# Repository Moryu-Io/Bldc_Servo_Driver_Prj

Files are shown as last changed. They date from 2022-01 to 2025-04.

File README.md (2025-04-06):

# BLDC Servo Driver Project

## 概要
STM32マイコンを使用してBLDCを駆動する制御プログラム  
マイコン種類が変わっても、なるべくペリフェラル設定のメンテのみで動作が可能なように実装  
現在のメイン開発は`G431CB_FSDmini`

新ROBO-剣出場ロボット[Quinque](https://www.robo-one.com/rankings/view/1127)のアーム部モータに採用  
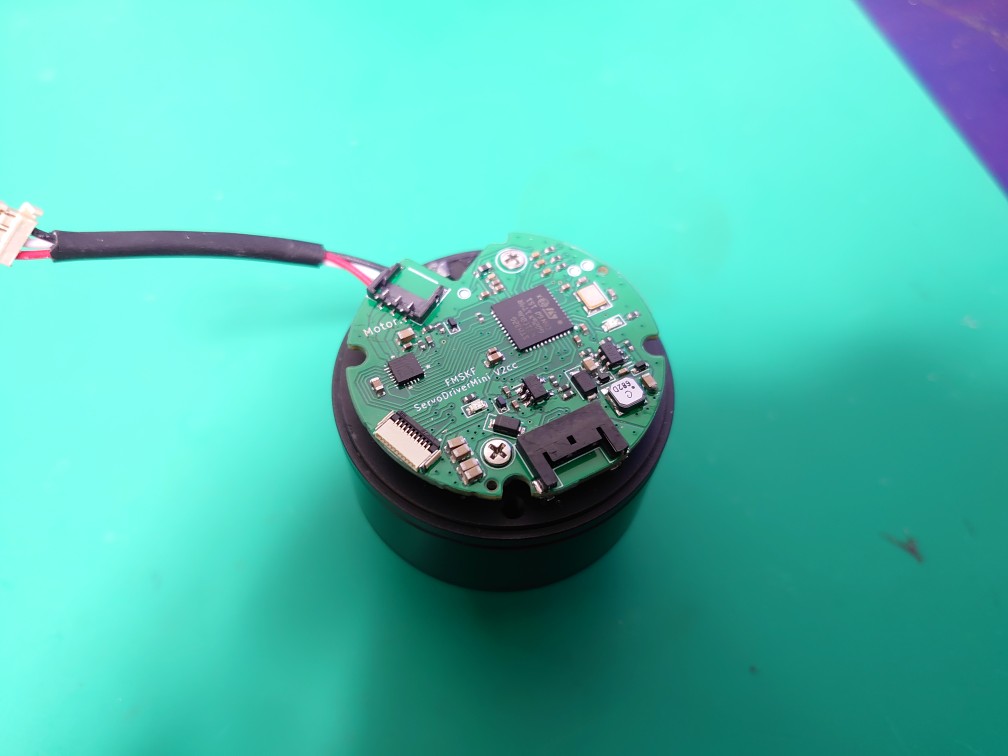
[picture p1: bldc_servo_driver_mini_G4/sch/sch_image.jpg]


## フォルダ構成
| フォルダ名 | 説明 |
| --- | --- |
|bldc_servo_driver_mini_F4|STM32F405を使用したBLDCドライバ用コード(未メンテ)|
|bldc_servo_driver_mini_G4|STM32G4系マイコンを使用したBLDCドライバ用コード|
|bldc_servo_driver_mini_H7|STM32H7を使用したBLDCドライバ用コード(未作成)|
|bldc_servo_driver_stspin32g4|STM32G4(STSPIN32G4)を使用したBLDCドライバ用コード|
|common|各マイコンで共通のコード。例えばBLDCベクトル制御ロジック|
|python|各テストコマンドをpython経由で使用するためのスクリプト群|

## 使い方(Windows)
1. 必要Toolのインストール
    - VScode
    - GNU ARM Embedded Toolchain
        - [公式サイト](https://developer.arm.com/tools-and-software/open-source-software/developer-tools/gnu-toolchain/gnu-rm/downloads)
        - Projectとしては2020-q4を使っている。本PJのtask.jsonに記載のディレクトリを変えれば別Verでも使えるはず
        - zip版をDLし, C:\Tools\gcc-arm-none-eabi-9-20XX-qX-major-win32\bin など分かりやすいように配置し、Path を通しておく
    - makeするための何か
        - make for windows, msys2, wslなど。自分は現状msys2でmakeを使えるようにしている
        - 本PJのtask.jsonでは`C:\\msys64\\usr\\bin\\make.exe` がある前提で記載している
    - STM32CubeProgrammer
        - [公式サイト]https://www.st.com/ja/development-tools/stm32cubeprog.html
        - STM32マイコンへのFW書き込みやフラッシュ制御などができる
        - 本PJのtask.jsonではコマンドライン用のexeを利用してマイコンへの書き込みを行っている

2. クローン
    - `git clone https://github.com/Moryu-Io/Bldc_Servo_Driver_Prj.git`など
    - VSCode のタスク構成もついてくるはず

3. VSCode Workspaceを開く
    - 現在は`bldc_servo_driver_G4.code-workspace`推奨

4. Ctrl+Alt+t でタスクを開き`Build project`を実行すると、ビルドができる

5. Ctrl+Alt+t でタスクを開き`cube_program`を実行すると書き込みができる

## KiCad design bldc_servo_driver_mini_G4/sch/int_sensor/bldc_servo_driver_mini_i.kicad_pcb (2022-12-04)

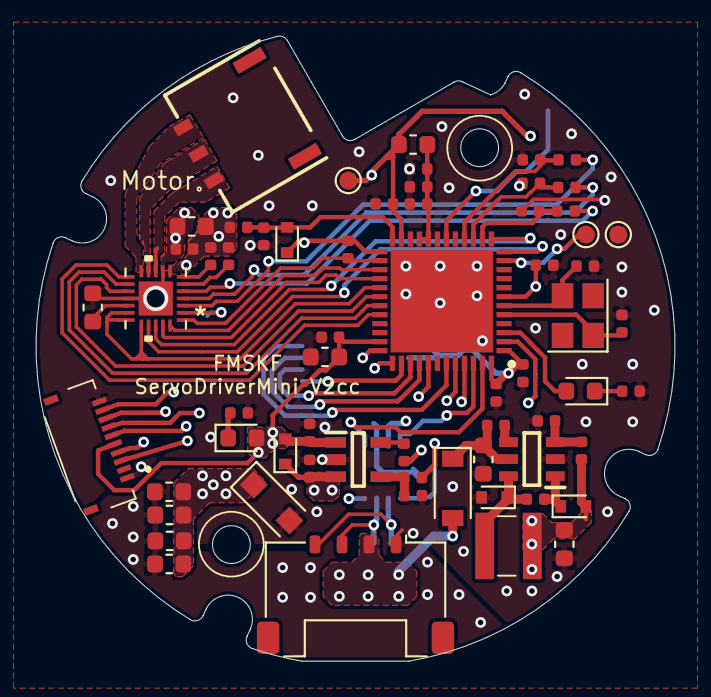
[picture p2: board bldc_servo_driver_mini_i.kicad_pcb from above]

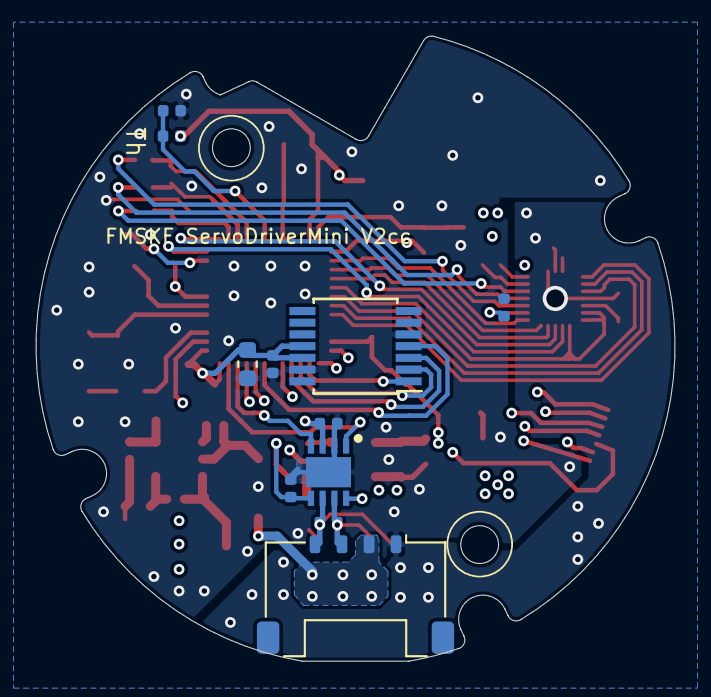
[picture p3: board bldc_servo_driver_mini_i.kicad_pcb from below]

Board: 4 copper layers, 35.5 x 34.7 mm, 74 parts (11 on the bottom side), 56 nets.

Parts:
C1, C2, C3, C4, C7, C8, C10, C16, C20, C21, C24, C32: 0.1u; C_0402_1005Metric
C5, C11, C15, C22, C28, C29, C30, C31: 10u; C_0603_1608Metric
C6, C13: 0.01u; C_0402_1005Metric
C9, C14, C23: 1u; C_0402_1005Metric
C12, C25: 4.7u; C_0603_1608Metric
C17, C18, C19: 220pF; C_0402_1005Metric
C26, C27: 8p; C_0402_1005Metric
D1: D_Schottky; D_SOD-123F
D2: PMEG6010AESBYL; D_SOD-123
D3, D4, D9: D_Schottky; D_SOD-523
D5: BAT30KFILM; D_SOD-523
D6, D8: LED; LED_0603_1608Metric
IC1: ST730MR; SOT95P280X145-5N
IC2: LT1616ES6#TRMPBF; SOT95P280X90-6N
IC3: TLT9251VLEXUMA1; SON65P300X300X110-9N
IC4: STM32G4xxyU; QFN50P700X700X60-49N-D
J1: 1-2328702-0; 123287020
J2, J3: Conn_01x04; Molex_Pico-Lock_504050-0491_1x04-1MP_P1.50mm_Horizontal
J7: DF65-3P-1.7V_21_
L1: L; L_0603_1608Metric
L2: 4.7u; LPS3314332MRC
R3, R4, R16, R18, R20: 10k; R_0402_1005Metric
R5: 47k; R_0402_1005Metric
R6: 27k; R_0402_1005Metric
R7: 470k; R_0402_1005Metric
R8: 33k; R_0402_1005Metric
R9, R10, R11: 510; R_0402_1005Metric
R12, R14: 330; R_0402_1005Metric
R15: 60; R_0402_1005Metric
R17: 0; R_0402_1005Metric
R19: 30.1k or 51k(MP2359); R_0402_1005Metric
TH1: Thermistor_NTC; R_0402_1005Metric
TP1, TP2, TP3: TestPoint; TestPoint_Pad_D1.0mm
U1: AS5048A; TSSOP-14_4.4x5mm_P0.65mm
U2: PDRV8311HRRWR
Y1: Crystal; Crystal_SMD_Abracon_ABM8G-4Pin_3.2x2.5mm

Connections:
+3V3: C1.1, C2.1, C5.2, C7.2, C9.1, C10.1, C12.1, C20.1, C21.1, C32.2, D3.2, D5.1, D8.2, IC1.1, IC3.5, IC4.1, IC4.23, IC4.25, IC4.35, IC4.48, J1.5, L1.2, R5.2, R16.1, R18.2, TP1.1, U1.11, U1.12, U2.2
+5V: C8.1, C16.1, C29.2, D3.1, D9.2, IC1.3, IC3.3, L2.2, R4.1, R19.2
+12V: C11.2, C22.1, C23.1, C24.1, C28.2, C30.2, C31.2, D1.1, D2.2, J2.2, J3.2, R7.2, R17.1, U2.8
/CAN1_EN: IC3.8, IC4.2
/CAN1_RX: IC3.4, IC4.46
/CAN1_TX: IC3.1, IC4.47
/CAN_H: IC3.7, J2.3, J3.3, R15.2
/CAN_L: IC3.6, J2.4, J3.4, R15.1
/CurrentSensA: C17.1, IC4.14, R9.1
/CurrentSensB: C18.1, IC4.15, R10.1
/CurrentSensC: C19.1, IC4.16, R11.1
/DAC_O1_GAIN: IC4.12, U2.21
/DAC_O2_SLEW: IC4.13, U2.22
/GPIO_MODE: IC4.28, U2.23
/LED1: D6.2, IC4.3
/M_OUTA: J7.1, U2.10
/M_OUTB: J7.2, U2.11
/M_OUTC: J7.3, U2.12
/NRST: C3.1, IC4.7, J1.4
/Potentio_Sens: IC4.11, TP2.1
/SOA: R9.2, U2.5
/SOB: R10.2, U2.4
/SOC: R11.2, U2.3
/SPI3_CS: IC4.38, U1.1
/SPI3_MISO: IC4.40, U1.3
/SPI3_MOSI: IC4.43, U1.4
/SPI3_SCK: IC4.39, U1.2
/SWCLK: IC4.37, J1.7
/SWDIO: IC4.36, J1.6
/SWO: IC4.41, J1.3
/TIM1_CH1: IC4.30, U2.15
/TIM1_CH1N: IC4.29, U2.18, U2.19, U2.20
/TIM1_CH2: IC4.31, U2.14
/TIM1_CH3: IC4.32, U2.13
/Temp_Sens: IC4.18, R18.1, TH1.1
/USART1_RX: IC4.45, J1.9
/USART1_TX: IC4.44, J1.8
/Vm_Sens: D5.2, IC4.24, R7.1, R8.2
/nFAULT: IC4.26, R16.2, U2.1
/nSLEEP: IC4.27, U2.24
GND: C1.2, C2.2, C3.2, C4.2, C5.1, C7.1, C8.2, C9.2, C10.2, C11.1, C12.2, C13.2, C14.2, C15.1, C16.2, C17.2, C18.2, C19.2, C20.2, C21.2, C22.2, C24.2, C25.1, C26.1, C27.2, C28.1, C29.1, C30.1, C31.1, C32.1, D1.2, D4.2, IC1.2, IC2.2, IC3.2, IC3.9, IC4.49, J1.1, J1.10, J2.1, J3.1, R6.1, R8.1, R12.1, R14.1, R20.1, TH1.2, TP3.1, U1.5, U1.13, U2.9, U2.16, U2.25
unnamed: C6.1, D9.1, IC2.1
unnamed: C6.2, D4.1, IC2.6, L2.1
unnamed: C4.1, C13.1, C14.1, IC4.20, IC4.21, L1.1
unnamed: C15.2, D2.1, IC2.5, R3.2
unnamed: C23.2, U2.6
unnamed: C25.2, U2.17
unnamed: C26.2, IC4.5, Y1.1
unnamed: C27.1, IC4.6, Y1.3
unnamed: D6.1, R12.2
unnamed: D8.1, R14.2
unnamed: IC1.4, R5.1, R6.2
unnamed: IC1.5, R4.2
unnamed: IC2.3, R19.1, R20.2
unnamed: IC2.4, R3.1
unnamed: R17.2, U2.7

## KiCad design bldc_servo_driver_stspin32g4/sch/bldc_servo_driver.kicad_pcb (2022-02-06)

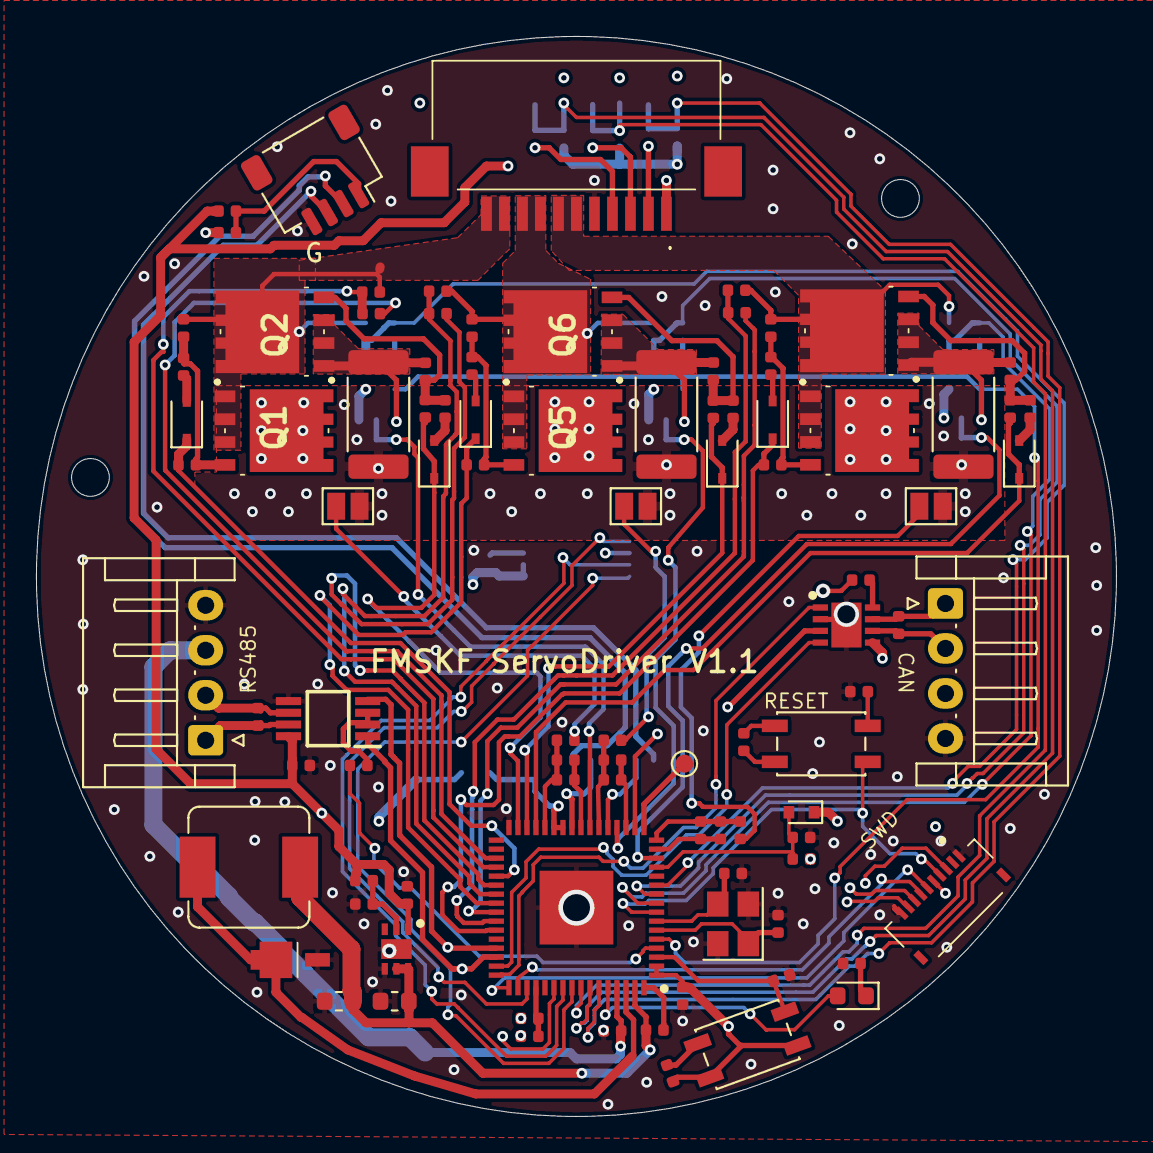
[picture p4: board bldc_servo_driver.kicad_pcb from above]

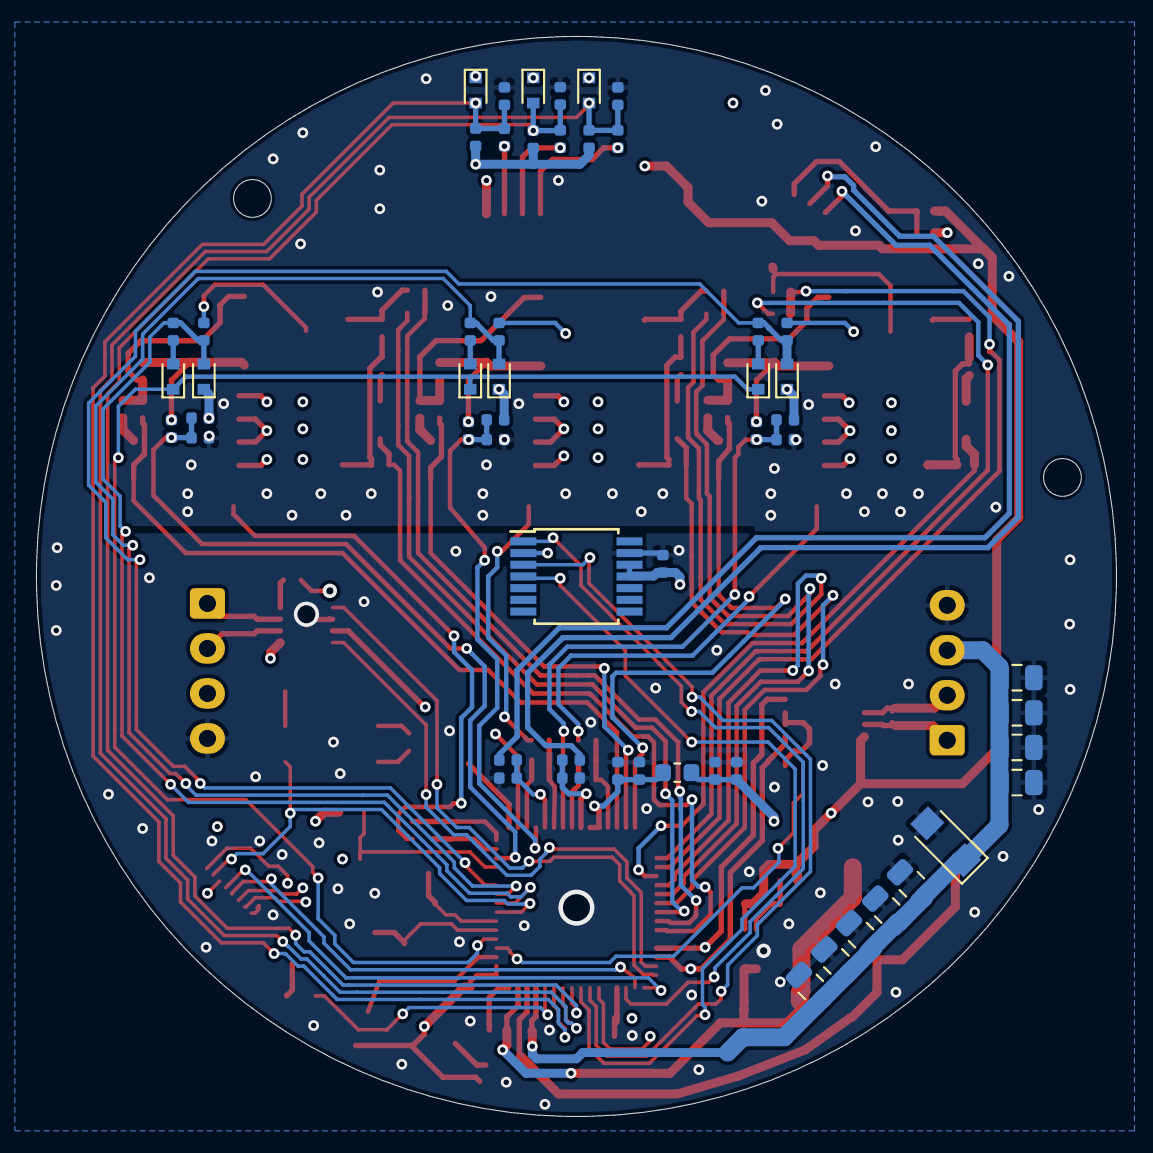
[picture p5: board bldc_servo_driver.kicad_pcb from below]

Board: 4 copper layers, 60.0 x 60.0 mm, 150 parts (54 on the bottom side), 97 nets.

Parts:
C1, C2, C3: 10p; C_0402_1005Metric
C4, C8, C20, C25, C50, C52: 0.1u; C_0402_1005Metric
C7: 2.2u; C_0402_1005Metric
C9, C26: 10u; C_0603_1608Metric
C10, C27, C28, C42: 1u; C_0402_1005Metric
C11: 0.01u; C_0402_1005Metric
C12, C14, C15, C17, C19, C29, C30, C31, C32: 22u; C_0805_2012Metric
C13, C16, C22: C; C_0402_1005Metric
C18, C21, C46: 100p; C_0402_1005Metric
C23, C24: 0.001u; C_0402_1005Metric
C53: 4.7u; C_0402_1005Metric
D1, D2, D3, D4, D5, D6, D7, D8, D9, D10: BAT30KFILM; D_SOD-523
D11: SMM4F24A; D_SMF
D12: STPS1L40M
D13: LED; LED_0603_1608Metric
D17, D18, D19, D20, D21, D22: BAT48JFILM; D_SOD-323
H1, H2: MountingHole; MountingHole_2.1mm
IC1: STSPIN32G4; QFN50P900X900X100-65N-D
IC3: LDFMPVR; SON65P200X200X100-7N-D
IC5: SN65HVD485EDGKR; SOP65P490X110-8N
IC6: TLT9251VLEXUMA1; SON65P300X300X110-9N
J1: 1-2328702-0; 123287020
J2, J3: Conn_01x04; JST_EH_S4B-EH_1x04_P2.50mm_Horizontal
J4: 52271-1179; 522711179
J5: Conn_01x04; JST_SH_SM04B-SRSS-TB_1x04-1MP_P1.00mm_Horizontal
JP1, JP2, JP3: SolderJumper_2_Bridged; SolderJumper-2_P1.3mm_Open_Pad1.0x1.5mm
L1: L; L_0603_1608Metric
L2: 33u; L_Sumida_CDMC6D28_7.25x6.5mm
Q1, Q2, Q3, Q4, Q5, Q6: STL180N6F7; STL140N6F7
R1, R5, R7: 1.8k; R_0402_1005Metric
R2, R3, R4, R6, R10, R11, R25, R51, R53, R54, R56, R68, R69, R71: 10k; R_0402_1005Metric
R8: 470k; R_0402_1005Metric
R9: 33k; R_0402_1005Metric
R12, R13, R14: 2.2k; R_0402_1005Metric
R15, R16, R17, R18, R19, R20, R70: 22k; R_0402_1005Metric
R21, R22, R23, R28, R31, R33: 1.5k; R_0402_1005Metric
R24: 52.3k; R_0402_1005Metric
R26, R42: 1k; R_0402_1005Metric
R27, R29, R32: 11k; R_0402_1005Metric
R30, R34, R35, R40, R41, R44, R45, R47, R55, R57, R60, R61, R65, R66: 0; R_0402_1005Metric
R36: 60; R_0402_1005Metric
R37: 120; R_0402_1005Metric
R43: 330; R_0402_1005Metric
R46, R49, R50, R52, R64, R67: 33; R_0402_1005Metric
R48, R58, R59: 0.003; R_2512_6332Metric
R62, R63: 1.6k; R_0402_1005Metric
SW1, SW2: SW_SPST; SW_SPST_EVQP2
TP1: TestPoint; TestPoint_Pad_D1.0mm
U1: AS5048A; TSSOP-14_4.4x5mm_P0.65mm
Y1: ABM8G-25MHZ-18-D2Y-T; Crystal_SMD_Abracon_ABM8G-4Pin_3.2x2.5mm

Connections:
+3.3VA: C10.2, C11.2, IC1.26, IC1.27, L1.2
+3V3: C4.1, C8.1, C50.1, C52.1, C53.1, D1.1, D2.1, D3.1, D4.1, D5.1, D7.1, D8.1, IC1.1, IC1.2, IC6.5, J1.5, L1.1, R6.2, R10.2, R11.2, R15.1, R17.1, R19.1, R41.1, R70.1, SW2.1, U1.11, U1.12
+5V: C7.1, C22.1, IC3.1, IC5.8, IC6.3, J4.1, R24.2, R40.1
+BATT: C12.1, C14.1, C15.1, C17.1, C19.1, C20.1, C29.1, C30.1, C31.1, C32.1, D11.1, IC1.61, J2.3, J3.3, Q1.5, Q1.6, Q1.7, Q1.8, Q1.9, Q3.5, Q3.6, Q3.7, Q3.8, Q3.9, Q5.5, Q5.6, Q5.7, Q5.8, Q5.9, R8.2
/subSch_3phasebridge/BOOT0: C42.1, IC1.41
/subSch_3phasebridge/BOOT1: C28.1, IC1.38
/subSch_3phasebridge/BOOT2: C27.1, IC1.35
/subSch_3phasebridge/GHS0: D19.1, IC1.43, R50.2
/subSch_3phasebridge/GHS1: D20.1, IC1.40, R64.2
/subSch_3phasebridge/GHS2: D17.1, IC1.37, R46.2
/subSch_3phasebridge/GLS0: D21.1, IC1.29, R52.2
/subSch_3phasebridge/GLS1: D22.1, IC1.30, R67.2
/subSch_3phasebridge/GLS2: D18.1, IC1.31, R49.2
/subSch_3phasebridge/MotorD0: J4.6, J4.7, Q3.1, Q3.2, Q3.3, Q4.5, Q4.6, Q4.7, Q4.8, Q4.9, R2.1, R54.2, R55.1
/subSch_3phasebridge/MotorD1: J4.8, J4.9, Q5.1, Q5.2, Q5.3, Q6.5, Q6.6, Q6.7, Q6.8, Q6.9, R3.1, R57.1, R68.2
/subSch_3phasebridge/MotorD2: J4.10, J4.11, Q1.1, Q1.2, Q1.3, Q2.5, Q2.6, Q2.7, Q2.8, Q2.9, R4.1, R44.1, R51.2
/subSch_3phasebridge/VshuntU+: Q4.1, Q4.2, Q4.3, R21.2, R56.2, R58.1
/subSch_3phasebridge/VshuntU-: JP2.2, R28.2
/subSch_3phasebridge/VshuntV+: Q6.1, Q6.2, Q6.3, R22.2, R59.1, R69.2
/subSch_3phasebridge/VshuntV-: JP3.2, R31.2
/subSch_3phasebridge/VshuntW+: Q2.1, Q2.2, Q2.3, R23.2, R48.1, R53.2
/subSch_3phasebridge/VshuntW-: JP1.2, R33.2
/subSch_extcon/ANALOG0: J5.2, R62.1
/subSch_extcon/ANALOG1: J5.3, R63.1
/subSch_extcon/ANALOG2: IC1.17, TP1.1
/subSch_extcon/CAN_EN: IC1.4, R34.1, R35.2
/subSch_extcon/COM_BUS3: IC1.45, IC5.4, J1.8
/subSch_extcon/COM_BUS4: IC1.46, IC5.1, J1.9
/subSch_extcon/Hall_0: J4.3, R1.1
/subSch_extcon/Hall_1: J4.4, R5.1
/subSch_extcon/Hall_2: J4.2, R7.1
/subSch_extcon/USART_EN: IC5.2, IC5.3, R34.2
/subSch_mcu/CAN1_RX: IC1.47, IC6.4
/subSch_mcu/CAN1_TX: IC1.48, IC6.1
/subSch_mcu/HALL_AD_A: C23.1, IC1.25, R62.2
/subSch_mcu/HALL_AD_B: C24.1, IC1.21, R63.2
/subSch_mcu/HALL_U: C1.1, D5.2, IC1.57, R1.2, R6.1
/subSch_mcu/HALL_V: C2.1, D7.2, IC1.58, R5.2, R10.1
/subSch_mcu/HALL_W: C3.1, D8.2, IC1.59, R7.2, R11.1
/subSch_mcu/LED: D13.2, IC1.60
/subSch_mcu/MCU_OUT0: C42.2, IC1.42, R55.2
/subSch_mcu/MCU_OUT1: C28.2, IC1.39, R57.2
/subSch_mcu/MCU_OUT2: C27.2, IC1.36, R44.2
/subSch_mcu/MCU_SPI_BUS0: IC1.56, U1.4
/subSch_mcu/MCU_SPI_BUS1: IC1.55, U1.3
/subSch_mcu/MCU_SPI_BUS2: IC1.18, U1.2
/subSch_mcu/MCU_SPI_BUS3: IC1.51, U1.1
/subSch_mcu/MCU_SWD_BUS0: IC1.50, J1.7
/subSch_mcu/MCU_SWD_BUS1: IC1.49, J1.6
/subSch_mcu/MCU_SWD_BUS2: C25.1, IC1.8, J1.4, SW1.1
/subSch_mcu/MCU_SWD_BUS3: IC1.54, J1.3
/subSch_mcu/MCU_VBAT_MON: D4.2, IC1.13, R8.1, R9.2
/subSch_mcu/OP1M: C46.2, IC1.16, R27.2, R28.1
/subSch_mcu/OP1O: C46.1, IC1.15, R27.1
/subSch_mcu/OP2M: C18.2, IC1.22, R29.2, R31.1
/subSch_mcu/OP2O: C18.1, IC1.19, R29.1
/subSch_mcu/OP3M: C21.2, IC1.28, R32.2, R33.1
/subSch_mcu/OP3O: C21.1, IC1.24, R32.1
/subSch_mcu/SCREF: IC1.52, R70.2, R71.1
/subSch_mcu/SW: D12.1, D12.2, IC1.62, L2.2
/subSch_mcu/USER_SW: C8.2, IC1.3, R26.1, SW2.2
/subSch_onboardsensing/BEMF0: D1.2, IC1.9, R2.2, R12.1
/subSch_onboardsensing/BEMF1: D2.2, IC1.10, R3.2, R13.1
/subSch_onboardsensing/BEMF2: D3.2, IC1.11, R4.2, R14.1
/subSch_onboardsensing/CurFb+_0: IC1.14, R15.2, R16.1, R21.1
/subSch_onboardsensing/CurFb+_1: IC1.20, R17.2, R18.1, R22.1
/subSch_onboardsensing/CurFb+_2: IC1.23, R19.2, R20.1, R23.1
/subSch_onboardsensing/GPIO_BEMF: D6.1, D9.1, D10.1, IC1.5
GND: C1.2, C2.2, C3.2, C4.2, C7.2, C9.2, C10.1, C11.1, C12.2, C13.2, C14.2, C15.2, C16.1, C17.2, C19.2, C20.2, C22.2, C23.2, C24.2, C26.2, C29.2, C30.2, C31.2, C32.2, C50.2, C52.2, C53.2, D11.2, D12.3, IC1.32, IC1.65, IC3.4, IC3.7, IC5.5, IC6.2, IC6.9, J1.1, J1.10, J2.4, J3.4, J4.5, J5.4, JP1.1, JP2.1, JP3.1, R9.1, R16.2, R18.2, R20.2, R25.1, R26.2, R42.2, R43.2, R48.2, R58.2, R59.2, R71.2, U1.13, Y1.2, Y1.4
unnamed: C13.1, IC1.6, Y1.1
unnamed: C16.2, IC1.7, Y1.3
unnamed: C25.2, R42.1, SW1.2
unnamed: D6.2, R12.2
unnamed: D9.2, R13.2
unnamed: D10.2, R14.2
unnamed: D13.1, R43.1
unnamed: D17.2, R45.2
unnamed: D18.2, R47.2
unnamed: D19.2, R60.2
unnamed: D20.2, R61.2
unnamed: D21.2, R65.2
unnamed: D22.2, R66.2
unnamed: IC1.64, R30.2
unnamed: IC3.2, R24.1, R25.2
unnamed: IC5.6, J2.2, R36.2
unnamed: IC5.7, J2.1, R36.1
unnamed: IC6.6, J3.2, R37.1
unnamed: IC6.7, J3.1, R37.2
unnamed: IC6.8, R35.1
unnamed: J5.1, R40.2, R41.2
unnamed: Q1.4, R45.1, R46.1, R51.1
unnamed: Q2.4, R47.1, R49.1, R53.1
unnamed: Q3.4, R50.1, R54.1, R60.1
unnamed: Q4.4, R52.1, R56.1, R65.1
unnamed: Q5.4, R61.1, R64.1, R68.1
unnamed: Q6.4, R66.1, R67.1, R69.1
VCC: C9.1, C26.1, IC1.63, IC3.5, IC3.6, L2.1, R30.1

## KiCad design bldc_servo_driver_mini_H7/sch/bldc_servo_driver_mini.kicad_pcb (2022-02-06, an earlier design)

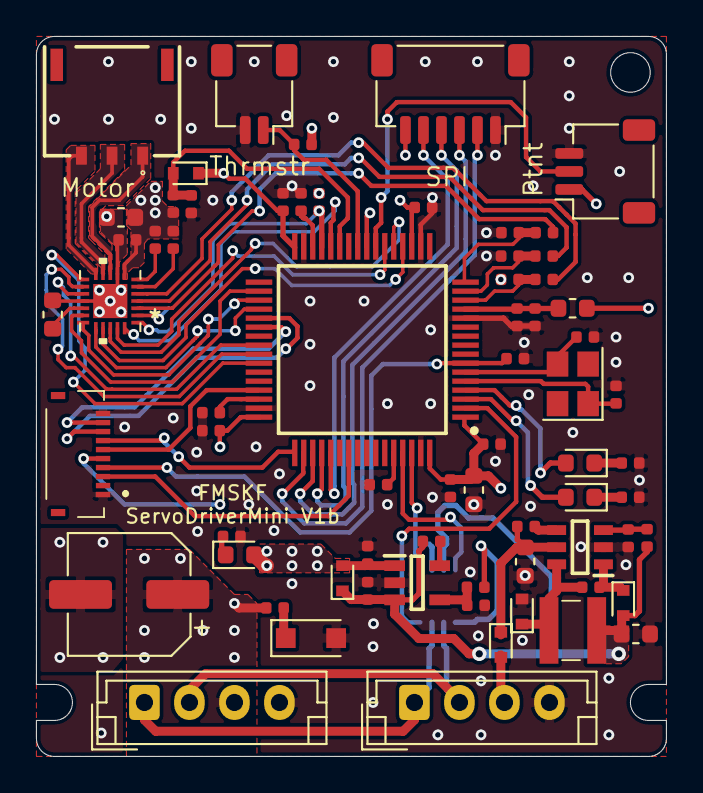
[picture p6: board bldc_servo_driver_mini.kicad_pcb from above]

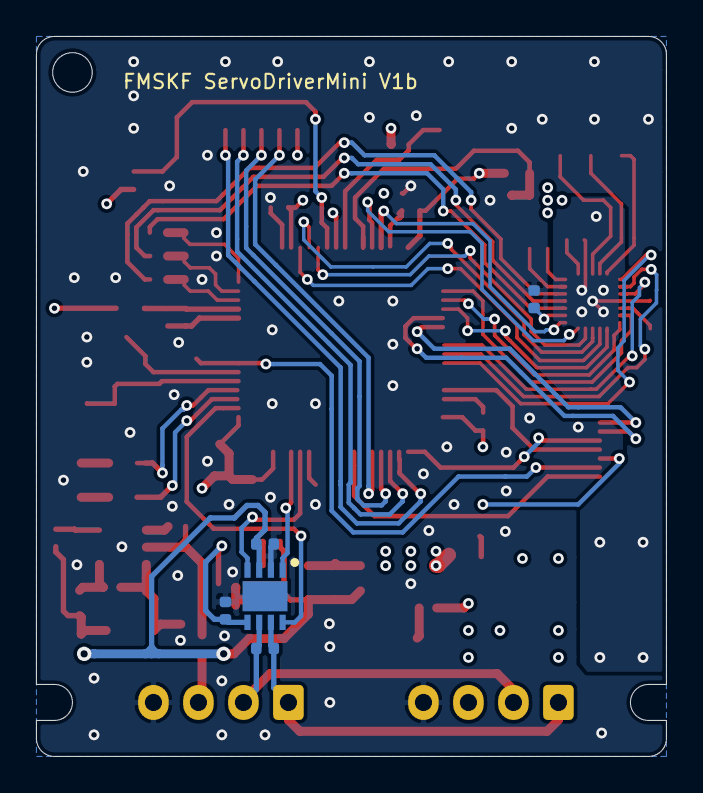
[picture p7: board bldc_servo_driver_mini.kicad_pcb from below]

Board: 4 copper layers, 35.0 x 40.0 mm, 73 parts (5 on the bottom side), 64 nets.

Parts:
C1, C3, C4, C7, C8, C10, C11, C13, C16, C20, C21, C24: 0.1u; C_0402_1005Metric
C2, C5: 2.2u; C_0402_1005Metric
C6: 0.01u; C_0402_1005Metric
C9, C14, C23: 1u; C_0402_1005Metric
C12, C25: 4.7u; C_0603_1608Metric
C15, C22, C29: 10u; C_0603_1608Metric
C17, C18, C19: 22pF; C_0402_1005Metric
C26, C27: 8p; C_0402_1005Metric
C28: 47u; CP_Elec_6.3x7.7
D1: D_Schottky; D_SOD-123F
D2: PMEG6010AESBYL; D_SOD-523
D3, D4, D9: D_Schottky; D_SOD-523
D5: BAT30KFILM; D_SOD-523
D6, D7, D8: LED; LED_0603_1608Metric
IC1: ST730MR; SOT95P280X145-5N
IC2: LT1616ES6#TRMPBF; SOT95P280X90-6N
IC3: TLT9251VLEXUMA1; SON65P300X300X110-9N
J1: 1-2328702-0; 123287020
J2, J3: Conn_01x04; JST_EH_B4B-EH-A_1x04_P2.50mm_Vertical
J4: Conn_01x06; JST_SH_SM06B-SRSS-TB_1x06-1MP_P1.00mm_Horizontal
J5: Conn_01x03; JST_SH_SM03B-SRSS-TB_1x03-1MP_P1.00mm_Horizontal
J6: Conn_01x02; JST_SH_SM02B-SRSS-TB_1x02-1MP_P1.00mm_Horizontal
J7: DF65-3P-1.7V_21_
L1: L; L_0603_1608Metric
L2: 4.7u; LPS3314332MRC
R1: 100; R_0402_1005Metric
R2: R; R_0402_1005Metric
R3, R4, R16, R18, R20: 10k; R_0402_1005Metric
R5: 47k; R_0402_1005Metric
R6: 27k; R_0402_1005Metric
R7: 470k; R_0402_1005Metric
R8: 33k; R_0402_1005Metric
R9, R10, R11, R12, R13, R14: 330; R_0402_1005Metric
R15: 60; R_0402_1005Metric
R17: 0; R_0402_1005Metric
R19: 30.1k; R_0402_1005Metric
U1: STM32H7A3RGT6; QFP50P1200X1200X160-64N
U2: PDRV8311HRRWR
Y1: Crystal; Crystal_SMD_Abracon_ABM8G-4Pin_3.2x2.5mm

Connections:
+3V3: C1.1, C4.1, C7.1, C9.1, C10.1, C11.1, C12.1, C20.1, C21.1, D3.2, D5.1, D8.2, IC1.1, IC3.5, J1.5, J4.6, J5.1, L1.2, R5.2, R16.1, R18.2, U1.1, U1.19, U1.24, U1.32, U1.48, U1.64, U2.2
+5V: C8.1, C16.1, C29.2, D3.1, D9.2, IC1.3, IC3.3, L2.2, R4.1, R19.2
+12V: C22.1, C23.1, C24.1, C28.1, D2.2, J2.3, J3.3, R1.2, R7.2, R17.1, U2.8
/CAN1_EN: IC3.8, U1.2
/CAN1_RX: IC3.4, U1.61
/CAN1_TX: IC3.1, U1.62
/CAN_H: IC3.7, J2.1, J3.1, R15.2
/CAN_L: IC3.6, J2.2, J3.2, R15.1
/CurrentSensA: C17.1, R9.1, U1.14
/CurrentSensB: C18.1, R10.1, U1.15
/CurrentSensC: C19.1, R11.1, U1.16
/DAC_O1_GAIN: U1.20, U2.21
/DAC_O2_SLEW: U1.21, U2.22
/GPIO_MODE: U1.22, U2.23
/LED1: D6.2, U1.3
/LED2: D7.2, U1.4
/M_OUTA: J7.1, U2.10
/M_OUTB: J7.2, U2.11
/M_OUTC: J7.3, U2.12
/NRST: C3.1, J1.4, U1.7
/Potentio_Sens: J5.2, U1.23
/SOA: R9.2, U2.5
/SOB: R10.2, U2.4
/SOC: R11.2, U2.3
/SPI3_CS: J4.2, U1.50
/SPI3_MISO: J4.4, U1.52
/SPI3_MOSI: J4.5, U1.53
/SPI3_SCK: J4.3, U1.51
/SWCLK: J1.7, U1.49
/SWDIO: J1.6, U1.45
/SWO: J1.3, U1.55
/TIM1_CH1: U1.40, U2.15
/TIM1_CH1N: U1.34, U2.18
/TIM1_CH2: U1.41, U2.14
/TIM1_CH2N: U1.35, U2.19
/TIM1_CH3: U1.42, U2.13
/TIM1_CH3N: U1.36, U2.20
/Temp_Sens: J6.1, R18.1, U1.25
/USART6_RX: J1.9, U1.38
/USART6_TX: J1.8, U1.37
/Vm_Sens: D5.2, R7.1, R8.2, U1.27
/nFAULT: R16.2, U1.29, U2.1
/nSLEEP: U1.28, U2.24
GND: C1.2, C2.1, C3.2, C4.2, C5.2, C7.2, C8.2, C9.2, C10.2, C11.2, C12.2, C13.2, C14.2, C15.1, C16.2, C17.2, C18.2, C19.2, C20.2, C21.2, C22.2, C24.2, C25.1, C26.1, C27.2, C28.2, C29.1, D1.2, D4.2, IC1.2, IC2.2, IC3.2, IC3.9, J1.1, J1.10, J2.4, J3.4, J4.1, J5.3, J6.2, R2.2, R6.1, R8.1, R12.1, R13.1, R14.1, R20.1, U1.12, U1.18, U1.31, U1.47, U1.63, U2.9, U2.16, U2.25
unnamed: C2.2, U1.30
unnamed: C5.1, U1.46
unnamed: C6.1, D9.1, IC2.1
unnamed: C6.2, D4.1, IC2.6, L2.1
unnamed: C13.1, C14.1, L1.1, U1.13
unnamed: C15.2, D2.1, IC2.5, R3.2
unnamed: C23.2, U2.6
unnamed: C25.2, U2.17
unnamed: C26.2, U1.5, Y1.1
unnamed: C27.1, U1.6, Y1.3
unnamed: D1.1, R1.1
unnamed: D6.1, R12.2
unnamed: D7.1, R13.2
unnamed: D8.1, R14.2
unnamed: IC1.4, R5.1, R6.2
unnamed: IC1.5, R4.2
unnamed: IC2.3, R19.1, R20.2
unnamed: IC2.4, R3.1
unnamed: R2.1, U1.60
unnamed: R17.2, U2.7

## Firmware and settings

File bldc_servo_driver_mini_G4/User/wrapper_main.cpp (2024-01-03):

#include "main.h"

#include "ext_com_manager.hpp"
#include "logger.hpp"
#include "servo_driver_model.hpp"
#include "wrapper_main.hpp"

#include "debug_printf.hpp"

volatile uint32_t u32_tim7_end_cnt = 0;

void cpp_wrapper_main_setup(void) {
  initialize_servo_driver_model();
}

void cpp_wrapper_main_loop(void) {
  loop_servo_driver_model();

  // debug_printf("%d\n", u32_tim7_end_cnt);
}

void USART1TX_DMATC_ITR() {
  get_debug_com()->tx_callback();
}

void TIM6_ITR() {
  //ext_com_manage_main();
}

void TIM7_ITR() {
  get_bldcservo_manager()->update();

  u32_tim7_end_cnt = TIM7->CNT;

  LOG::routine();
}

extern "C"
void HAL_FDCAN_RxFifo0Callback(FDCAN_HandleTypeDef *hfdcan, uint32_t RxFifo0ITs){
  ext_com_manage_main();
}

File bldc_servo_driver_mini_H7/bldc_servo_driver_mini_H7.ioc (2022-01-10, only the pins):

Mcu.UserName=STM32H7A3RGTx
PA0.Signal=ADC1_INP16
PA1.Signal=ADC1_INP17
PA10.Signal=S_TIM1_CH3
PA11.Signal=GPIO_Analog
PA13.Signal=DEBUG_JTMS-SWDIO
PA14.Signal=DEBUG_JTCK-SWCLK
PA15.Signal=GPIO_Output
PA2.Signal=ADCx_INP14
PA4.Signal=COMP_DAC11_group
PA5.Signal=COMP_DAC12_group
PA6.Signal=COMP_DAC21_group
PA7.Signal=ADCx_INP7
PA8.Signal=S_TIM1_CH1
PA9.Signal=S_TIM1_CH2
PB0.Signal=S_TIM3_CH3
PB1.Signal=ADCx_INP5
PB10.Signal=GPIO_Input
PB13.Signal=TIM1_CH1N
PB14.Signal=TIM1_CH2N
PB15.Signal=TIM1_CH3N
PB2.Signal=GPIO_Output
PB3.Signal=DEBUG_JTDO-SWO
PB4.Signal=S_TIM3_CH1
PB5.Signal=S_TIM3_CH2
PB6.Signal=USART1_TX
PB7.Signal=USART1_RX
PB8.Signal=FDCAN1_RX
PB9.Signal=FDCAN1_TX
PC10.Signal=SPI3_SCK
PC11.Signal=SPI3_MISO
PC12.Signal=SPI3_MOSI
PC13.Signal=GPIO_Output
PC2.Signal=GPIO_Output
PC3.Signal=GPIO_Output
PC4.Signal=ADCx_INP4
PC5.Signal=ADCx_INP8
PC6.Signal=USART6_TX
PC7.Signal=USART6_RX
PH0-OSC_IN.Signal=RCC_OSC_IN
PH1-OSC_OUT.Signal=RCC_OSC_OUT

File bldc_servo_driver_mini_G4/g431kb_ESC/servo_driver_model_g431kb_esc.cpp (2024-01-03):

#include "fdcan.h"

#include "adcc.hpp"
#include "canc.hpp"
#include "spic.hpp"
#include "pwminc.hpp"
#include "uart_dmac.hpp"
#include "debug_printf.hpp"
#include "logger.hpp"
#include "iir.hpp"
#include "mymath.hpp"
#include "controller.hpp"
#include "version.hpp"

#include "debug_command.hpp"
#include "servo_driver_model.hpp"

#include "bldc.hpp"
#include "bldc_drive_method.hpp"
#include "bldc_mode_base.hpp"
#include "bldc_mode_pos_control.hpp"
#include "bldc_mode_trq_control.hpp"
#include "bldc_mode_test.hpp"
#include "bldc_servo_manager.hpp"

#include "flash_interface.hpp"

/************************ VERSION ******************************/
uint16_t U16_CHIP_LOCAL_VER = 0x0100;
/***************************************************************/

enum ADC1CH {
  CurFb_U,   // CH3,  PA2
  CurFb_W,   // CH12, PB1
  //Potentio,  // CH11, PB12
  MotorTemp, // CH5,  PB14
  //VmSens,    // CH1,  PA0
};
static ADCC<3> Adc1Ctrl(ADC1, DMA1, LL_DMA_CHANNEL_1);

enum ADC2CH {
  CurFb_V, // CH3, PA6
  VmSens,  // CH1, PA0
  //BEMF_U,  // CH17, PA4
  //BEMF_V,  // CH5, PC4
  //BEMF_W,  // CH14, PB11 -> SPI3CS
};
static ADCC<2> Adc2Ctrl(ADC2, DMA1, LL_DMA_CHANNEL_2);


// TODO:角度補間が必要かもしれない
class OutAngSenser : public PWMINC {
public:
  using PWMINC::PWMINC;

  void update() override {
    PWMINC::update();

    if(isCapEdge){
      u16_edge2ege_cnt = u16_no_edge_cnt + 1;
      u16_no_edge_cnt = 0;
      u16_angle_digit_14b_preEdge = u16_angle_digit_14b_nowEdge;
      //uint32_t  u32_pre  = (uint32_t)U16_PRE_CNT * u16_cap_rise_edge / U16_FRAME_CNT;
      uint32_t  u32_data = (uint32_t)u16_cap_fall_edge * U16_FRAME_CNT / u16_cap_rise_edge;

      if(u32_data < U16_PRE_CNT) u32_data = U16_PRE_CNT;

      u16_angle_digit_14b_nowEdge = (u32_data - U16_PRE_CNT) << 2;
      u16_angle_digit_14b = u16_angle_digit_14b_nowEdge;
    } else {
      int16_t _s16_d_ang = u16_angle_digit_14b_nowEdge - u16_angle_digit_14b_preEdge;
      _s16_d_ang =  (_s16_d_ang > 0x1FFF)  ? (_s16_d_ang - 0x3FFF)
                  :((_s16_d_ang < -0x1FFF) ? (_s16_d_ang + 0x3FFF)
                                            : _s16_d_ang );
      u16_no_edge_cnt = u16_no_edge_cnt + 1;
      u16_angle_digit_14b = u16_angle_digit_14b_nowEdge 
                            + u16_no_edge_cnt * _s16_d_ang / u16_edge2ege_cnt;
      u16_angle_digit_14b = u16_angle_digit_14b & 0x3FFF;
    }
  }

  uint16_t get_angle_cnt() { return u16_angle_digit_14b; }

private:
  const uint16_t U16_PRE_CNT   = 12 + 4;
  const uint16_t U16_FRAME_CNT = 4119;

  uint16_t u16_angle_digit_14b;
  uint16_t u16_angle_digit_14b_nowEdge;
  uint16_t u16_angle_digit_14b_preEdge;

  uint16_t u16_no_edge_cnt;
  uint16_t u16_edge2ege_cnt = 10;
};

static OutAngSenser OutAngSenserCtrl(TIM2, 36, 5000);

extern "C"{
void TIM2_IRQHandler(void){ OutAngSenserCtrl.intr(); }
}

class MotorAngSenser : public SPIC {
public:
  MotorAngSenser(SPI_TypeDef *_spi) : SPIC(_spi){};

protected:
  void select() override { LL_GPIO_ResetOutputPin(GPIOB, LL_GPIO_PIN_11); };
  void deselect() override { LL_GPIO_SetOutputPin(GPIOB, LL_GPIO_PIN_11); };
};
static MotorAngSenser MotorAngSenserCtrl(SPI3);

float fl_now_ang_deg_debug = 0.0f;
float fl_now_elec_ang_deg_debug = 0.0f;
class PM3505: public BLDC {
public:
  PM3505()
    :iir_cur_u(0.778, 0.111, 0.111),
     iir_cur_v(0.778, 0.111, 0.111),
     iir_cur_w(0.778, 0.111, 0.111),
     iir_vellpf(0.96f, 0.02f, 0.02f) {};

  void init() override {
    /* init the motor angle senser */
    MotorAngSenserCtrl.init();

    LL_OPAMP_Enable(OPAMP1);
    LL_OPAMP_Enable(OPAMP2);
    LL_OPAMP_Enable(OPAMP3);

    /* PWM */
    LL_TIM_EnableUpdateEvent(TIM1);
    LL_TIM_EnableIT_UPDATE(TIM1);
    LL_TIM_EnableCounter(TIM1);
    // カウント開始してからRCレジスタを変えることで、UEVタイミングを変更
    // 20kHzでUEV発生
    LL_TIM_SetRepetitionCounter(TIM1, 1);
    LL_TIM_GenerateEvent_UPDATE(TIM1);
    TIM1->BDTR |= TIM_BDTR_MOE;
    TIM1->CCR1 = 0;
    TIM1->CCR2 = 0;
    TIM1->CCR3 = 0;
    TIM1->CCR4 = 4200;    // ADC用トリガ生成(TIM1OC4REF→TIM1TRG→ADC1,2)
    //LL_GPIO_SetOutputPin(GPIOC, LL_GPIO_PIN_6); // PWML HIGH

    /* ADC用トリガタイマ(TIM3) */

    LL_mDelay(1);
    //LL_GPIO_SetOutputPin(GPIOB, LL_GPIO_PIN_5); // GPIO_BEMF

    /* 電流制限値 */
    fl_current_lim_A_ = 1.0f;
  };

  void update_lowrate() override {
    //fl_Vm_ = Adc1Ctrl.get_adc_data(ADC1CH::VmSens) * Vm_Gain_ADtoV;
    fl_Vm_ = 12.0f;
  };

  void update() override {
    // OutAngSenserCtrl.update();

    /* 電気角測定 */
    uint16_t txdata = 0xFFFF;
    uint16_t rxdata = 0;

    MotorAngSenserCtrl.send_bytes(&txdata, &rxdata, 1);
    int32_t ang       = rxdata & 0x3FFF;    // 14bit Absolute Encoder
    int32_t delta_ang = ang - s32_pre_angle_raw;
    delta_ang =  (delta_ang > 0x1FFF)  ? (delta_ang - 0x3FFF)
               :((delta_ang < -0x1FFF) ? (delta_ang + 0x3FFF)
                                        : delta_ang );
    s32_pre_angle_raw = ang;
    // s32_angle_rotor_count_ += delta_ang;
    s32_angle_rotor_count_ -= delta_ang;  // 逆方向のため

    fl_now_out_vel_dps_ = iir_vellpf.update(-(float)delta_ang * Angle_Gain_CNTtoDeg*20000.0f);
    fl_now_out_ang_deg_  = (float)(s32_angle_rotor_count_) * Angle_Gain_CNTtoDeg;
    fl_now_elec_ang_deg_ = ((float)(ang - s32_elec_angle_offset_CNT_) * fl_elec_angle_gain_CNTtoDeg_ - 90.0f)*(float)s8_elec_angle_dir_;
fl_now_ang_deg_debug = fl_now_out_ang_deg_;
fl_now_elec_ang_deg_debug = fl_now_elec_ang_deg_;
    /* 電流測定 */
    now_curr_raw_.U = Adc1Ctrl.get_adc_data(ADC1CH::CurFb_U);
    now_curr_raw_.V = Adc2Ctrl.get_adc_data(ADC2CH::CurFb_V);
    now_curr_raw_.W = Adc1Ctrl.get_adc_data(ADC1CH::CurFb_W);
    now_current_.U  = iir_cur_u.update(Curr_Gain_ADtoA * ((int32_t)now_curr_raw_.U - st_curr_raw_mid_.U));
    now_current_.V  = iir_cur_v.update(Curr_Gain_ADtoA * ((int32_t)now_curr_raw_.V - st_curr_raw_mid_.V));
    now_current_.W  = iir_cur_w.update(Curr_Gain_ADtoA * ((int32_t)now_curr_raw_.W - st_curr_raw_mid_.W));
  };

  void set_drive_duty(DriveDuty &_Vol) override {
    uint32_t u_duty = (uint32_t)(mymath::satf(_Vol.Duty.U * Vm_inv, 1.0f, 0.0f) * (float)TIM1->ARR);
    uint32_t v_duty = (uint32_t)(mymath::satf(_Vol.Duty.V * Vm_inv, 1.0f, 0.0f) * (float)TIM1->ARR);
    uint32_t w_duty = (uint32_t)(mymath::satf(_Vol.Duty.W * Vm_inv, 1.0f, 0.0f) * (float)TIM1->ARR);
    TIM1->CCR1      = u_duty;
    TIM1->CCR2      = v_duty;
    TIM1->CCR3      = w_duty;
    set_enable_register(_Vol.u8_U_out_enable, _Vol.u8_V_out_enable, _Vol.u8_W_out_enable);
  };

  bool get_fault_state() override {
    return !LL_GPIO_IsInputPinSet(GPIOB, LL_GPIO_PIN_13);
  };

  bool get_ready_state() override {
    return true;
  }
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

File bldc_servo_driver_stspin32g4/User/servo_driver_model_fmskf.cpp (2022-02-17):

#include "adcc.hpp"
#include "bldc.hpp"
#include "bldc_drive_method.hpp"
#include "dacc.hpp"
#include "debug_printf.hpp"
#include "gate_drive_controller.hpp"
#include "mymath.hpp"
#include "servo_driver_model.hpp"
#include "uart_dmac.hpp"


enum ADC1CH {
  CurFb_U, // CH3,  PA2
  CurFb_W, // CH12, PB1
  Bemf_U,  // CH6,  PC0
  Bemf_V,  // CH7,  PC1
  Bemf_W,  // CH8,  PC2
  TempSens // TEMP
};
static ADCC<6> Adc1Ctrl(ADC1, DMA2, LL_DMA_CHANNEL_1);

enum ADC2CH {
  CurFb_V,  // CH3,  PA6
  AD_A,     // CH12, PB2
  AD_B,     // CH5,  PC4
  VBAT_MON, // CH1,  PA0
};
static ADCC<4> Adc2Ctrl(ADC2, DMA2, LL_DMA_CHANNEL_2);

class Maxon_BLDC : public BLDC {
public:
  Maxon_BLDC(){};

  void init() override {
    /* HallSensor */
    LL_TIM_EnableIT_CC1(TIM4);
    LL_TIM_CC_EnableChannel(TIM4, LL_TIM_CHANNEL_CH1);
    LL_TIM_EnableCounter(TIM4);

    /* PWM */
    LL_TIM_EnableUpdateEvent(TIM1);
    LL_TIM_EnableCounter(TIM1);
    TIM1->BDTR |= TIM_BDTR_MOE;
    TIM1->CCR1 = 0;
    TIM1->CCR2 = 0;
    TIM1->CCR3 = 0;
    //LL_TIM_OC_SetMode(TIM1, LL_TIM_CHANNEL_CH1, LL_TIM_OCMODE_PWM1);
    //LL_TIM_OC_SetMode(TIM1, LL_TIM_CHANNEL_CH2, LL_TIM_OCMODE_PWM1);
    //LL_TIM_OC_SetMode(TIM1, LL_TIM_CHANNEL_CH3, LL_TIM_OCMODE_PWM1);
    //LL_TIM_CC_EnableChannel(TIM1, LL_TIM_CHANNEL_CH1 | LL_TIM_CHANNEL_CH1N |
    //                              LL_TIM_CHANNEL_CH2 | LL_TIM_CHANNEL_CH2N |
    //                              LL_TIM_CHANNEL_CH3 | LL_TIM_CHANNEL_CH3N );
  };

  void hall_itr_callback() override {
    uint32_t portb               = LL_GPIO_ReadInputPort(GPIOB);
    uint8_t  _u8_next_hall_state = (uint8_t)((portb >> 6) & 0b111);
    switch(_u8_next_hall_state) {
    case 1:
      if(u8_now_hall_state_ == 5)
        s8_now_motor_dir_ = 1;
      else if(u8_now_hall_state_ == 3)
        s8_now_motor_dir_ = -1;
      break;
    case 3:
      if(u8_now_hall_state_ == 1)
        s8_now_motor_dir_ = 1;
      else if(u8_now_hall_state_ == 2)
        s8_now_motor_dir_ = -1;
      break;
    case 2:
      if(u8_now_hall_state_ == 3)
        s8_now_motor_dir_ = 1;
      else if(u8_now_hall_state_ == 6)
        s8_now_motor_dir_ = -1;
      break;
    case 6:
      if(u8_now_hall_state_ == 2)
        s8_now_motor_dir_ = 1;
      else if(u8_now_hall_state_ == 4)
        s8_now_motor_dir_ = -1;
      break;
    case 4:
      if(u8_now_hall_state_ == 6)
        s8_now_motor_dir_ = 1;
      else if(u8_now_hall_state_ == 5)
        s8_now_motor_dir_ = -1;
      break;
    case 5:
      if(u8_now_hall_state_ == 4)
        s8_now_motor_dir_ = 1;
      else if(u8_now_hall_state_ == 1)
        s8_now_motor_dir_ = -1;
      break;
    }

    s32_angle_rotor_count_ += s8_now_motor_dir_;

    /* 電気角キャリブレーション用(いずれ自動化) */
    //uint16_t HallAd_A = Adc2Ctrl.get_adc_data(ADC2CH::AD_A);
    //uint16_t HallAd_B = Adc2Ctrl.get_adc_data(ADC2CH::AD_B);
    //float hallad_center_shift_A = (float)HallAd_A - 2048;
    //float hallad_center_shift_B = (float)HallAd_B - 2048;
    //float fl_hall_atan_deg = mymath::rad2deg(mymath::atan2f(hallad_center_shift_A, hallad_center_shift_B));
    //debug_printf("%d,%d,%d \n", u8_now_hall_state_, _u8_next_hall_state, (int)(fl_hall_atan_deg*10.0f));

    u8_now_hall_state_ = _u8_next_hall_state;
  };

  void set_drive_duty(DriveDuty &_Vol) override {
    uint32_t u_duty = (uint32_t)(mymath::satf(_Vol.Duty.U * Vm_inv, 1.0f, 0.0f) * (float)TIM1->ARR);
    uint32_t v_duty = (uint32_t)(mymath::satf(_Vol.Duty.V * Vm_inv, 1.0f, 0.0f) * (float)TIM1->ARR);
    uint32_t w_duty = (uint32_t)(mymath::satf(_Vol.Duty.W * Vm_inv, 1.0f, 0.0f) * (float)TIM1->ARR);
    TIM1->CCR1      = u_duty;
    TIM1->CCR2      = v_duty;
    TIM1->CCR3      = w_duty;
    set_enable_register(_Vol.u8_U_out_enable, _Vol.u8_V_out_enable, _Vol.u8_W_out_enable);
  };

  void update() override {
    uint16_t HallAd_A = Adc2Ctrl.get_adc_data(ADC2CH::AD_A);
    uint16_t HallAd_B = Adc2Ctrl.get_adc_data(ADC2CH::AD_B);
    float hallad_center_shift_A = (float)HallAd_A - 2048;
    float hallad_center_shift_B = (float)HallAd_B - 2048;
    float fl_hall_atan_deg = mymath::rad2deg(mymath::atan2f(hallad_center_shift_A, hallad_center_shift_B));
    float fl_now_elec_ang_deg_  = (fl_hall_atan_deg - 71.5f + 22.5f) * 4.0f;  // 機械角→電気角変換
  }

  bool get_fault_state() override {
    return ((LL_GPIO_ReadInputPort(GPIOE) & GPIO_PIN_14) != GPIO_PIN_14);
  };
  bool get_ready_state() override {
    return ((LL_GPIO_ReadInputPort(GPIOE) & GPIO_PIN_15) == GPIO_PIN_15);
  }

private:
  const float Vm_inv = 1.0f / 12.0f;

  inline void set_enable_register(uint8_t Uenable, uint8_t Venable, uint8_t Wenable) {
    ///*
    if(Uenable == DRIVE_OUT_BOTH_ENABLE) {
      LL_TIM_OC_SetMode(TIM1, LL_TIM_CHANNEL_CH1, LL_TIM_OCMODE_PWM1);
      LL_TIM_CC_EnableChannel(TIM1, LL_TIM_CHANNEL_CH1 | LL_TIM_CHANNEL_CH1N);
    } else if(Uenable == DRIVE_OUT_LOW_ENABLE) {
      LL_TIM_OC_SetMode(TIM1, LL_TIM_CHANNEL_CH1, LL_TIM_OCMODE_ACTIVE);
      LL_TIM_CC_DisableChannel(TIM1, LL_TIM_CHANNEL_CH1);
      LL_TIM_CC_EnableChannel(TIM1, LL_TIM_CHANNEL_CH1N);
    } else {
      LL_TIM_OC_SetMode(TIM1, LL_TIM_CHANNEL_CH1, LL_TIM_OCMODE_INACTIVE);
      LL_TIM_CC_DisableChannel(TIM1, LL_TIM_CHANNEL_CH1);
      LL_TIM_CC_DisableChannel(TIM1, LL_TIM_CHANNEL_CH1N);
    }

    if(Venable == DRIVE_OUT_BOTH_ENABLE) {
      LL_TIM_OC_SetMode(TIM1, LL_TIM_CHANNEL_CH2, LL_TIM_OCMODE_PWM1);
      LL_TIM_CC_EnableChannel(TIM1, LL_TIM_CHANNEL_CH2 | LL_TIM_CHANNEL_CH2N);
    } else if(Venable == DRIVE_OUT_LOW_ENABLE) {
      LL_TIM_OC_SetMode(TIM1, LL_TIM_CHANNEL_CH2, LL_TIM_OCMODE_ACTIVE);
      LL_TIM_CC_DisableChannel(TIM1, LL_TIM_CHANNEL_CH2);
      LL_TIM_CC_EnableChannel(TIM1, LL_TIM_CHANNEL_CH2N);
    } else {
      LL_TIM_OC_SetMode(TIM1, LL_TIM_CHANNEL_CH2, LL_TIM_OCMODE_INACTIVE);
      LL_TIM_CC_DisableChannel(TIM1, LL_TIM_CHANNEL_CH2);
      LL_TIM_CC_DisableChannel(TIM1, LL_TIM_CHANNEL_CH2N);
    }
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

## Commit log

2022-01-08 copy from bldc_servo_driver_cpp repository
    [bldc_servo_driver.kicad_pcb, bldc_servo_driver.sch, subSch_3phasebridge.sch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]
2022-01-10 add : kicad projects of driver mini sch
    [bldc_servo_driver_mini.kicad_pcb, bldc_servo_driver_mini.sch]
2022-01-10 add : a gitignore file of g4 driver sch
2022-01-10 style :move peripheral driver files
2022-01-10 feat : [F4] enable debug printf
2022-01-12 feat : [F4] SPI for a magnet encoder
2022-01-12 feat : [F4] enable timer interrupt for servo and communication control
2022-01-15 feat : [F4] BLDC sine drive OK
2022-01-23 feat : [F4] enable ADC tigger
2022-01-23 feat : [F4] spi mode change to 16bit
2022-01-23 fix : [F4sch] generate 5V from DCDC
    [bldc_servo_driver_mini.kicad_pcb, bldc_servo_driver_mini.sch]
2022-02-06 fix : [F4sch] change a diode footprint of 5v line
    [bldc_servo_driver_mini.kicad_pcb, bldc_servo_driver_mini.sch]
2022-02-06 fix : [H7sch] apply F4sch update to H7sch
    [bldc_servo_driver_mini.kicad_pcb, bldc_servo_driver_mini.sch]
2022-02-06 fix : [G4sch] debug port FPC connector
    [bldc_servo_driver.kicad_pcb, bldc_servo_driver.sch, subSch_extcon.sch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]
2022-02-12 fix : [F4] enable printf of float variables
2022-02-12 feat : [F4] 3 phase current sensing
2022-02-12 feat : [F4] enable Vector Control of BLDC
2022-02-12 param : [F4] tuning current pid gain
2022-02-13 feat : [cmn] iir filter
2022-02-13 feat : [F4] position servo test
2022-02-13 fix : [cmn] fix double calculating I-Gain of PID
    [controller.hpp]
2022-02-13 fix : [F4] fix a angle direction of motor rotor
    [servo_driver_model_f4.cpp]
2022-02-16 refactor : [cmn] apply strategy pattern to bldc control class
2022-02-17 refactor : [cmn] bldc class menbers
2022-02-23 fix : [cmn] tune controller params
    [controller.hpp]
2022-02-23 feat : [F4] current step response test
2022-02-26 feat : [F4] servo calc time debug
2022-02-26 feat : [F4] torque on off cmd with CAN interface
2022-03-12 fix : [F4]bug fix
    [servo_driver_model_f4.cpp]
2022-03-12 feat : [cmn] can simulation by debug uart
2022-03-27 fix : [cmn]current step resp script
2022-05-06 feat : [G4]add a STM32G491 project
    [bldc_servo_driver_mini.kicad_pcb, bldc_servo_driver_mini.sch]
2022-05-06 fix : [G4]fix flash pase configs
    [servo_driver_model_g4.cpp]
2022-05-06 feat : [G4] current meas test
2022-05-06 feat : [G4] caribration ADC
2022-05-06 fix : [cmn] correct Vm(limit)
    [bldc_drive_method.cpp]
2022-05-06 fix : [G4] CAN filter setting
    [bldc_servo_driver_mini_G4.ioc, canc.cpp]
2022-05-06 fix : [G4] 3D models of sch
    [bldc_servo_driver_mini.kicad_pcb]
2022-05-16 feat : [G4] pid tune function
2022-06-01 feat : [G4] print func of version and build time
2022-06-29 feat : current limiter
2022-06-29 fix :[G4] CAN config
    [bldc_servo_driver_mini_G4.ioc]
2022-08-06 [G4] sch update
    [bldc_servo_driver_mini.kicad_pcb, bldc_servo_driver_mini.sch, bldc_servo_driver_mini_i.kicad_pcb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]
2022-12-04 fix : bldc servo driver mini sch
    [bldc_servo_driver_mini_i.kicad_pcb, bldc_servo_driver_mini_i.sch]
2023-01-21 refactor current pid gain setting
2023-01-29 feat : current control
2023-02-11 SPI setting for th modified ESC
2023-02-11 enable spi encoder (G4 ESC)
2023-02-12 [G4ESC] adjust current control parameters
2023-02-23 [g4esc] reduct current meas noises
    [g431kb_ESC.ioc, servo_driver_model_g431kb_esc.cpp]
2023-02-24 [g4esc] CAN trm pin output
2023-03-05 add adustment-test for currents mid
2023-04-16 [g431] sync timer1 pwm, controller, and adc
2023-04-20 [G431CBFSD] pwm adc sync
2023-05-04 g4esc adc trigger timing update
2023-05-05 g431esc : volt step resp test
2023-05-06 debug printf bug fix
2023-05-06 g431esc ff kv for current ctrl
2023-08-19 g4cb : current lpf
2024-01-03 add software spi com

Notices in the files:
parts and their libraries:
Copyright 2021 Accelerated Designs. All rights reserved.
